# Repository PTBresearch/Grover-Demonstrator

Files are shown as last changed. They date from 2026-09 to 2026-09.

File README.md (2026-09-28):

# Grover-Demonstrator
A simple hardware demonstrator to let the user experience classical search in unstructured data, vs the Grover quantum computer algorithm.

## What can it be used for?

- [Showing how (computationally) hard it is to find something in unstructured data](#showing-how-computationally-hard-it-is-to-find-something-in-unstructured-data)
- [Showing the "quantum advantage" that the Grover algorithm can provide](#showing-the-quantum-advantage-that-the-grover-algorithm-can-provide)
- [Showing the relationship between shots and the probability distribution](#showing-the-relationship-between-shots-and-the-probability-distribution)
- [Showing the impact of noise on the results of quantum computers / the Grover algorithm](#showing-the-impact-of-noise-on-the-results-of-quantum-computers--the-grover-algorithm)
- [Attracting people to a booth by having it blink](#attracting-people-to-a-booth-by-having-it-blink)

## Device overview

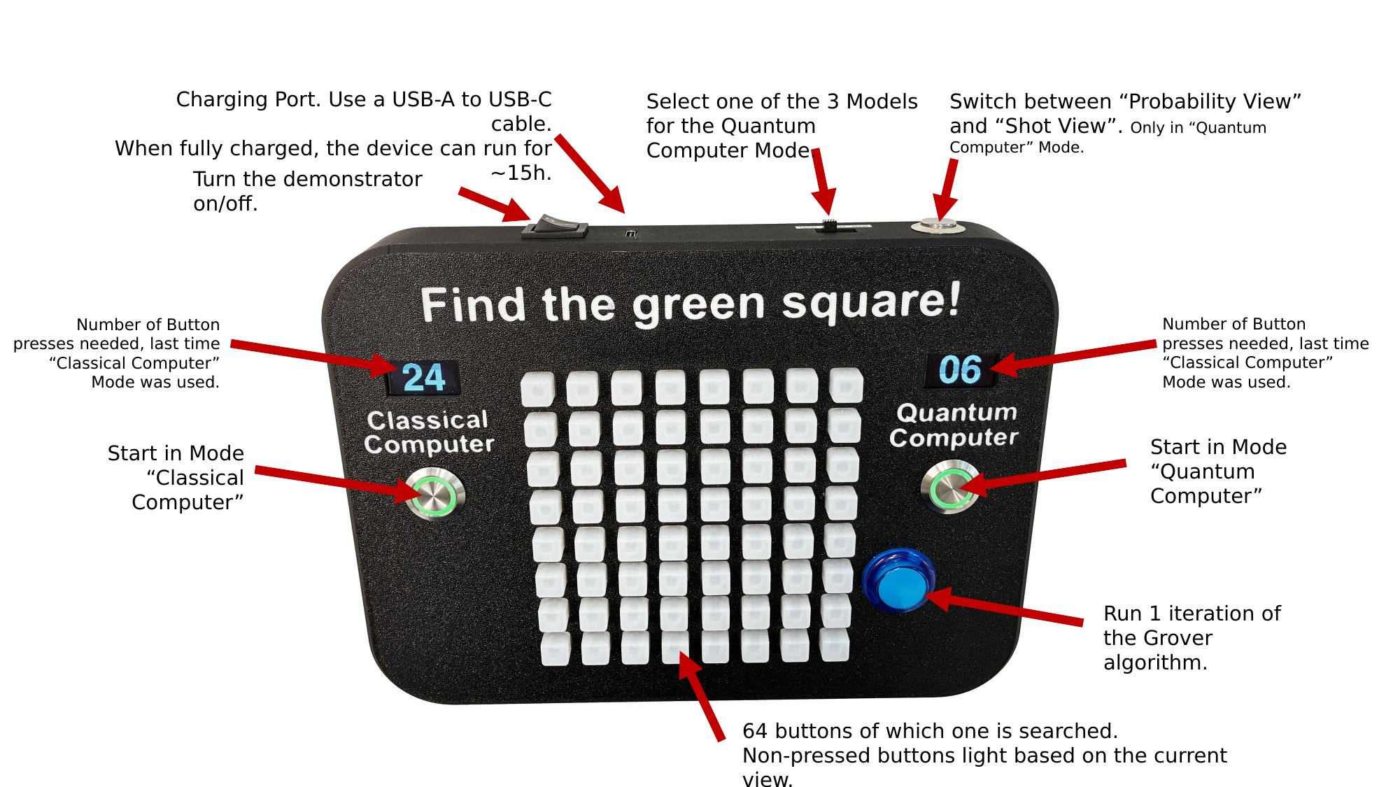
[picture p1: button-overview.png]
Annotated overview of the Grover Demonstrator


| Control | Description |
|---|---|
| On/off switch (top) | Turns the demonstrator on/off. |
| Charging port (top) | Use a USB-A to USB-C cable. When fully charged, the device can run for ~15 h. |
| Model slider (top) | Selects one of the 3 models for "Quantum Computer" mode. |
| Round button (top right) | Switches between "Probability View" and "Shot View". Only in "Quantum Computer" mode. |
| "Classical Computer" button | Starts in "Classical Computer" mode. |
| "Quantum Computer" button | Starts in "Quantum Computer" mode. |
| Left display | Number of button presses needed the last time "Classical Computer" mode was used. |
| Right display | Number of button presses needed the last time "Quantum Computer" mode was used. |
| Blue button | Runs 1 iteration of the Grover algorithm. |
| 8 × 8 button grid | 64 buttons, one of which is searched. Non-pressed buttons light up based on the current view. |

## Showing how (computationally) hard it is to find something in unstructured data

1. Start the demonstrator in "Classical Computer" mode and give it to a user.
2. Their task is to find the one button (of the 64 square ones) that blinks green when pushed.
3. This is an example of search in unstructured data: the user has no idea which button will light green.
4. You can discuss with them that with 64 buttons, they will need 32 tries on average.

A good example of search in unstructured data is guessing a password or decrypting data with no information about the key. You can verify that a solution is correct (you can try to decrypt the data), but there are no strategies to speed up the search. This is different from search problems with structured data, where you can, for example, sort the data to make it easier to search through.

Buttons that have not been pressed glow in a blue hue. The brighter they are, the more likely they are the correct button. As the data are unstructured, all buttons glow equally bright, but they become brighter as fewer buttons are left to be pressed.

> [!TIP]
> If the user found the green button in just a few steps, you can ask them or someone else to try again.

## Showing the "quantum advantage" that the Grover algorithm can provide

1. The user should have used/seen the "Classical Computer" mode already.
2. Make sure the demonstrator uses the **"Ideal"** model.
3. Start "Quantum Computer" mode. The user must again find the green button, ideally with fewer button presses. You can either let them search or do it yourself.

Again, buttons that have not been pressed glow in a blue hue. The brighter they are, the more likely they are the correct button. Initially, all buttons are equally bright, as there is no information about the correct result.

The user can "spend" a button press by pressing the blue button, which causes the Grover search algorithm to improve the prediction of the button that is searched.

When the blue button has been pressed 6 times, the prediction will be best. You can "undo" blue button presses by pressing the "Classical Computer" button. This is sometimes helpful when explaining the algorithm.

Thus, the optimal strategy seems to be to press the blue button once, then the brightest button. This strategy is less ideal with noise and high shot costs.

## Showing the relationship between shots and the probability distribution

1. The user should have used/seen the "Classical Computer" mode already.
2. Start "Quantum Computer" mode. The user must again find the green button, ideally with fewer button presses. You can either let them search or do it yourself.
3. Press the round button at the top of the device to switch to "Shot" mode.

In Shot mode, the buttons do not glow based on their likelihood. Instead, individual shots of the quantum computer are simulated. After the Grover algorithm is computed, the quantum state is read out, resulting in one random result based on the probabilities given by the quantum state of the qubits.

This mode makes it much more difficult to find the correct result without the ideal number of Grover algorithm iterations (blue button presses), especially when the "Real" model is used.

## Showing the impact of noise on the results of quantum computers / the Grover algorithm

1. The user should have used/seen the "Classical Computer" mode already.
2. Start "Quantum Computer" mode. The user must again find the green button, ideally with fewer button presses. You can either let them search or do it yourself.
3. When the blue Grover button has been pressed a few times, use the slider at the top to change between models:
   - **Ideal**: Simulation of a quantum computer without any noise/errors.
   - **Model**: Simple error model that introduces some gate errors.
   - **Real**: Results from a real IBM quantum computer.

The difference between the models is most easily visible when the buttons show probabilities, but Shot mode can also be used.

## Attracting people to a booth by having it blink

1. Start the device in "Quantum Computer" mode and press the round button on the top to switch to "Shot" mode.
2. Place the demonstrator so people can see the buttons blinking.

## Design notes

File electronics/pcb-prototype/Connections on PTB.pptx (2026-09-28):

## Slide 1

Displays

Trellis

BTN2

BTN3

BTN1

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
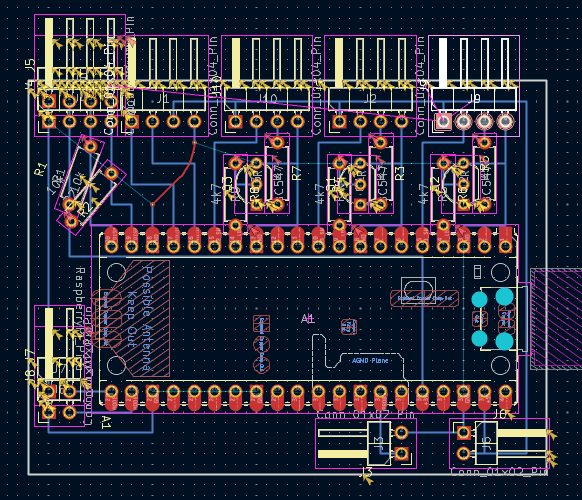
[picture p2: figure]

GND

GND

MODEL_1

MODEL_3

GND

GND

PROB_SW

5V

5V

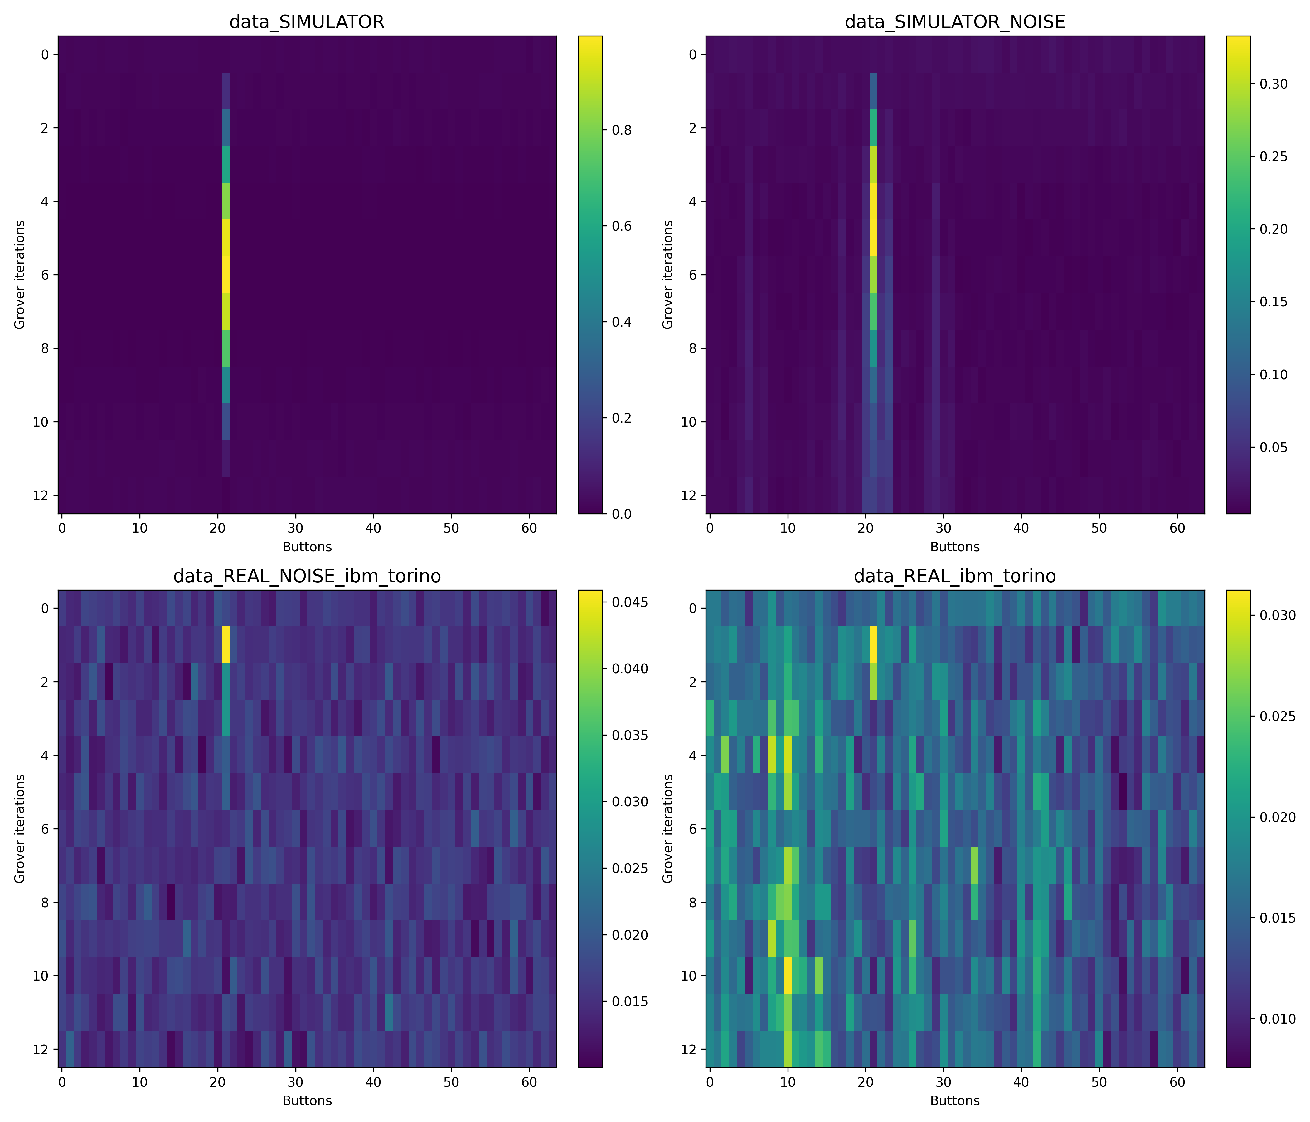
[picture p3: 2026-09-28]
qiskit/heatmaps.png

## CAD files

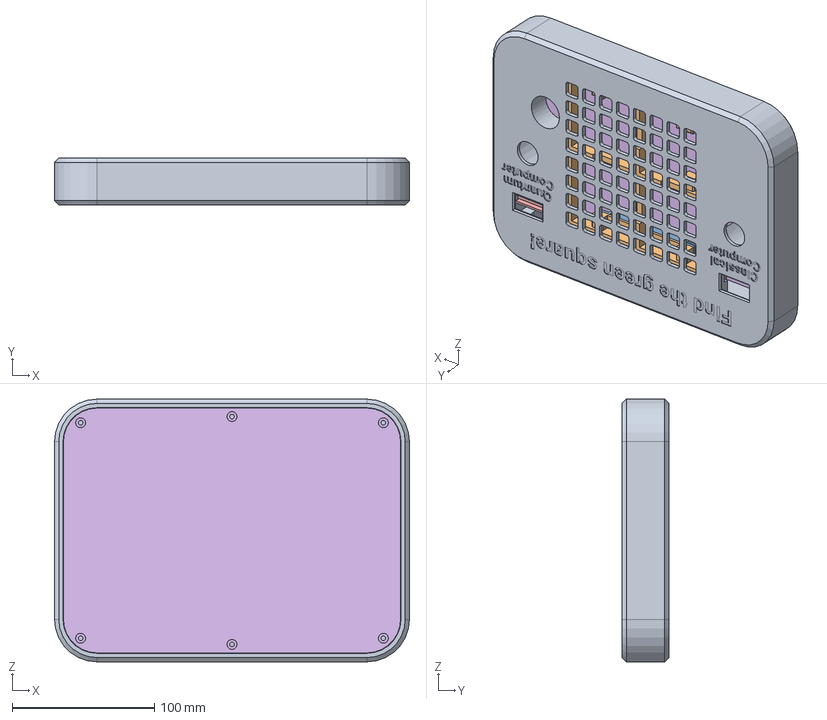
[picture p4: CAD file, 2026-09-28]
case/Grover.step
250.0 x 33.0 x 185.0 mm

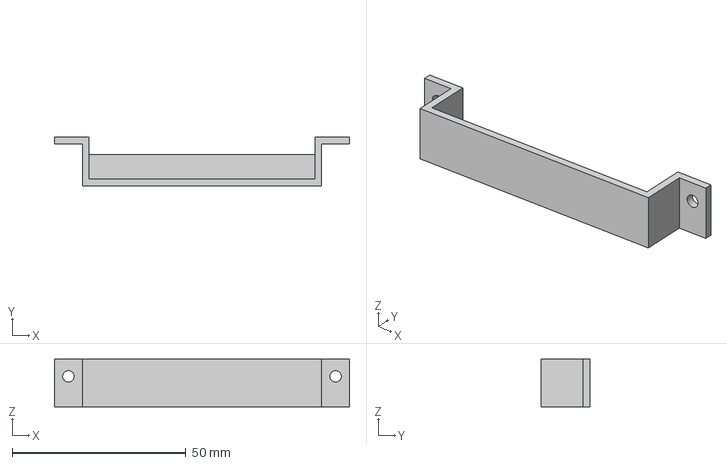
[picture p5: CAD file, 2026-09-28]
case/print files/Grover-v2-Halter-Akku-2x.3mf
85.0 x 14.0 x 13.8 mm

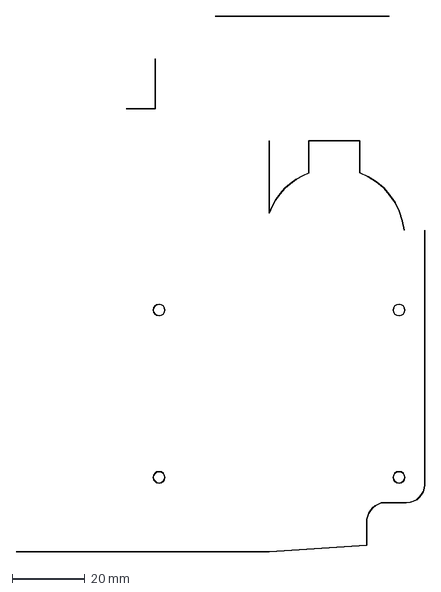
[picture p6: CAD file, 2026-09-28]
electronics/pcb/Skizze-Platine.dxf
112.2 x 147.4 mm

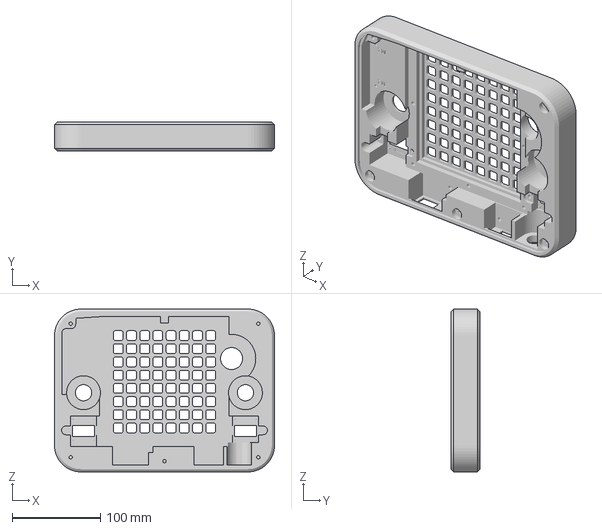
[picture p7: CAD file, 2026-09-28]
case/print files/Grover-v2.1-Gehäuse.3mf
250.0 x 33.0 x 185.0 mm

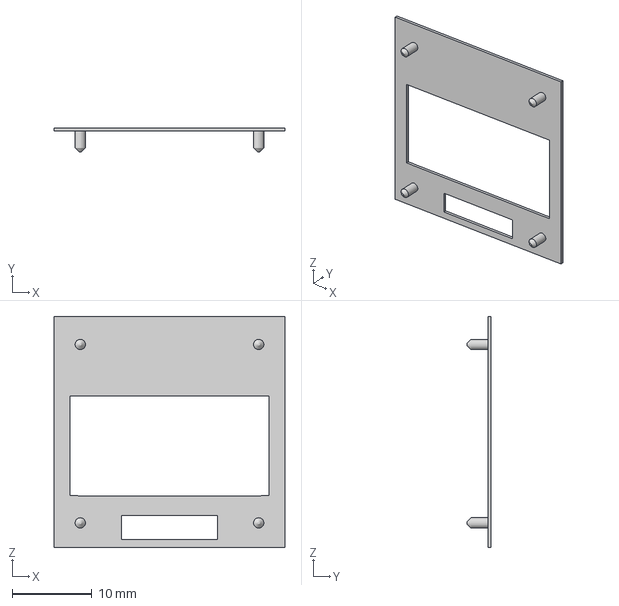
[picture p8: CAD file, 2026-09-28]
case/print files/Grover-v2-Zwischenplatte-Display.3mf
29.0 x 3.00 x 29.0 mm

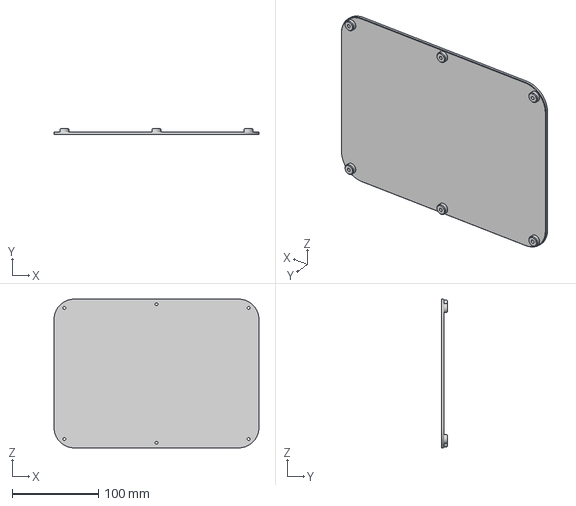
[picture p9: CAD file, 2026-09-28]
case/print files/Grover-v2-Backplate.3mf
237.4 x 6.70 x 172.4 mm

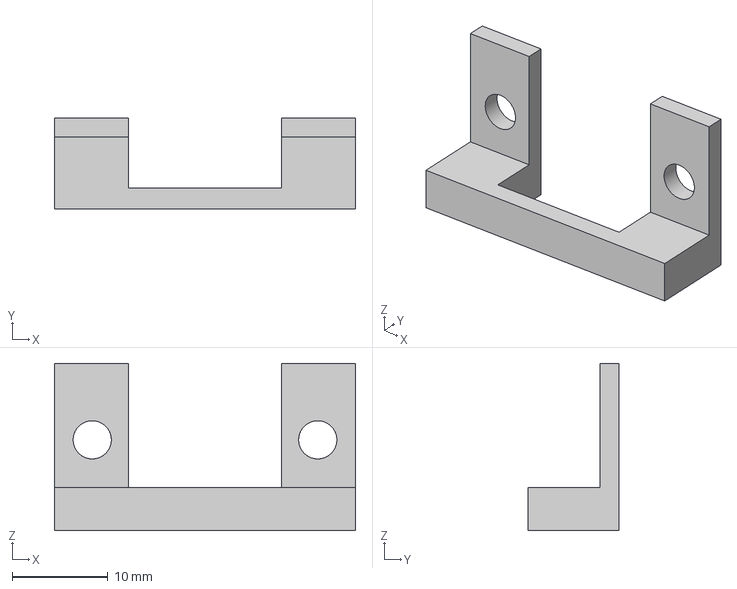
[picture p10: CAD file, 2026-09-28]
case/print files/Grover-v2-Halter-Schalter.3mf
31.5 x 9.50 x 17.5 mm

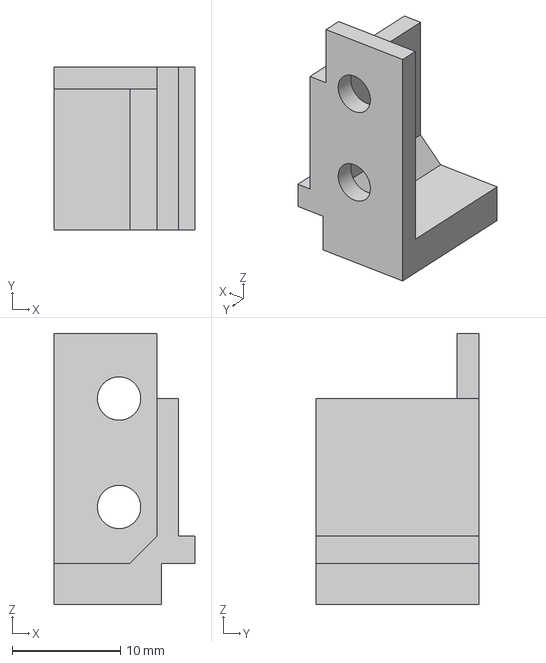
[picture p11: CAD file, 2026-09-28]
case/print files/Grover-v2-Halter-USB.3mf
13.0 x 15.0 x 25.0 mm

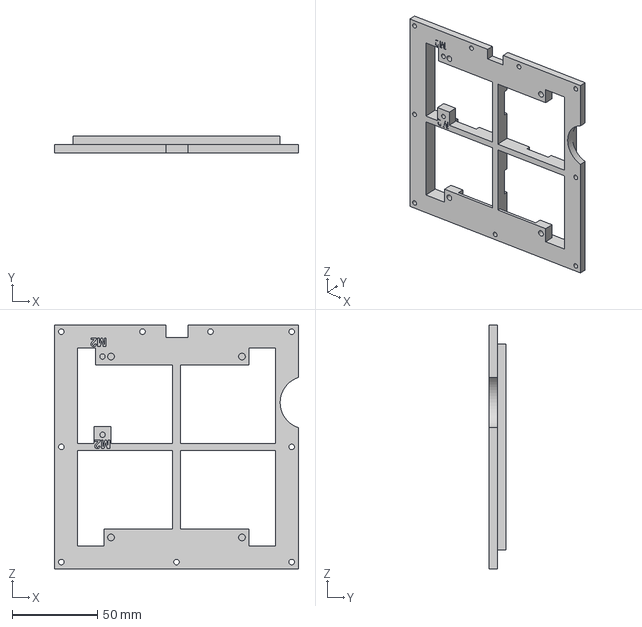
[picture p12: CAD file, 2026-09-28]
case/print files/Grover-v2-Halter-Trellis-1x.3mf
143.5 x 10.0 x 143.4 mm

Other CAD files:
case/print files/Grover-v2-Gehäuse.3mf
case/Grover.f3d

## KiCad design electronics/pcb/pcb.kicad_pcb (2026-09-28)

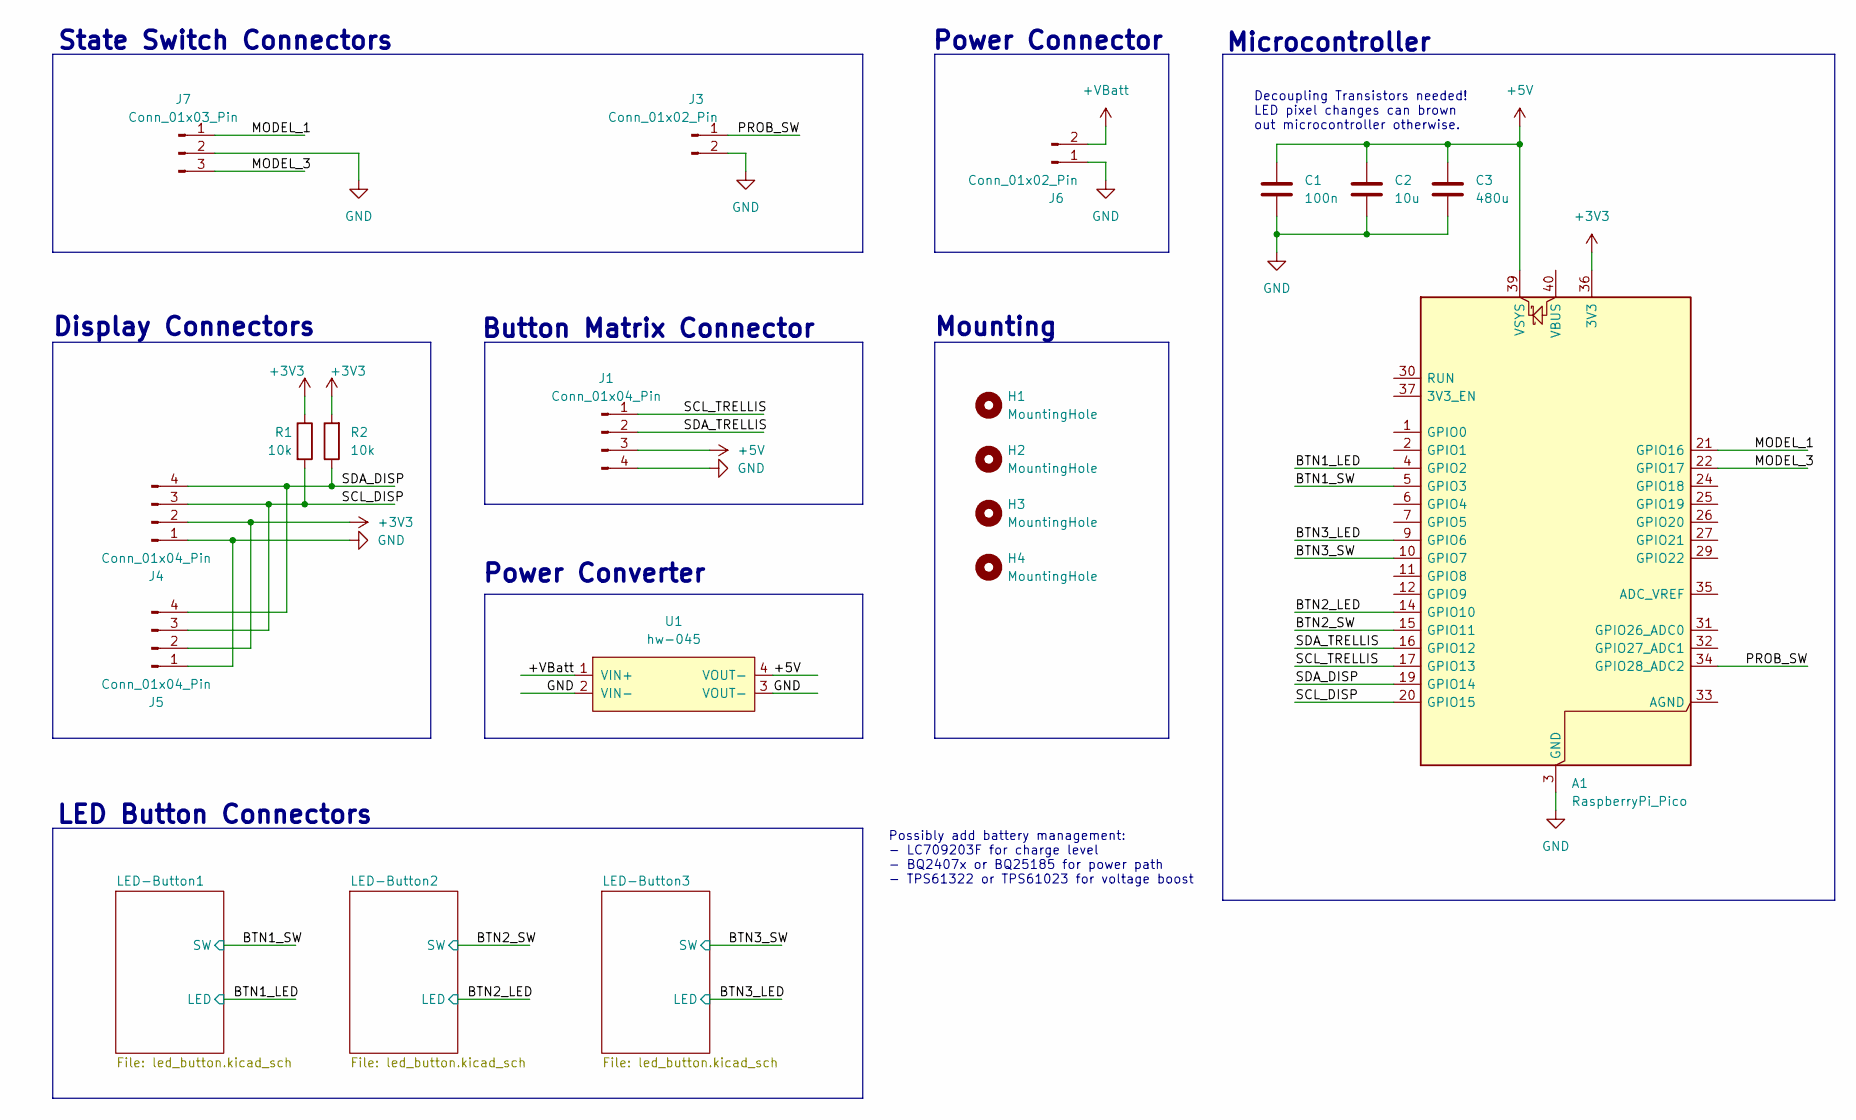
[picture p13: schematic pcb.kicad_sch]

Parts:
A1: RaspberryPi_Pico; RaspberryPi_Pico_Common_Unspecified
C1: 100n; C_Disc_D7.5mm_W5.0mm_P5.00mm
C2: 10u; CP_Radial_D5.0mm_P2.00mm
C3: 480u; CP_Radial_D12.5mm_P5.00mm
H1, H2, H3, H4: MountingHole; MountingHole_2.2mm_M2
J1, J4, J5: Conn_01x04_Pin; JST_PH_S4B-PH-K_1x04_P2.00mm_Horizontal
J3, J6: Conn_01x02_Pin; JST_PH_S2B-PH-K_1x02_P2.00mm_Horizontal
J7: Conn_01x03_Pin; JST_PH_S3B-PH-K_1x03_P2.00mm_Horizontal
R1, R2: 10k; R_Axial_DIN0309_L9.0mm_D3.2mm_P12.70mm_Horizontal
U1: hw-045

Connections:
+3V3: A1.36 (3V3), J4.2, J5.2, R1.1, R2.2
+5V: A1.39 (VSYS), C1.1, C2.1, C3.1, J1.3, U1.4 (VOUT-); also elsewhere on the board
+VBatt: J6.2, U1.1 (VIN+)
/BTN1_LED: A1.4 (GPIO2); also elsewhere on the board
/BTN1_SW: A1.5 (GPIO3); also elsewhere on the board
/BTN2_LED: A1.14 (GPIO10); also elsewhere on the board
/BTN2_SW: A1.15 (GPIO11); also elsewhere on the board
/BTN3_LED: A1.9 (GPIO6); also elsewhere on the board
/BTN3_SW: A1.10 (GPIO7); also elsewhere on the board
/MODEL_1: A1.21 (GPIO16), J7.1
/MODEL_3: A1.22 (GPIO17), J7.3
/PROB_SW: A1.34 (GPIO28_ADC2), J3.1
/SCL_DISP: A1.20 (GPIO15), J4.3, J5.3, R1.2
/SCL_TRELLIS: A1.17 (GPIO13), J1.1
/SDA_DISP: A1.19 (GPIO14), J4.4, J5.4, R2.1
/SDA_TRELLIS: A1.16 (GPIO12), J1.2
GND: A1.3 (GND), A1.8 (GND), A1.13 (GND), A1.18 (GND), A1.23 (GND), A1.28 (GND), A1.38 (GND), C1.2, C2.2, C3.2, J1.4, J3.2, J4.1, J5.1, J6.1, J7.2, U1.2 (VIN-), U1.3 (VOUT-); also elsewhere on the board

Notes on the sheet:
Display Connectors
State Switch Connectors
Possibly add battery management: - LC709203F for charge level - BQ2407x or BQ25185 for power path - TPS61322 or TPS61023 for voltage boost
Mounting
Power Converter
Power Connector
LED Button Connectors
Button Matrix Connector
Microcontroller
Decoupling Transistors needed! LED pixel changes can brown out microcontroller otherwise.

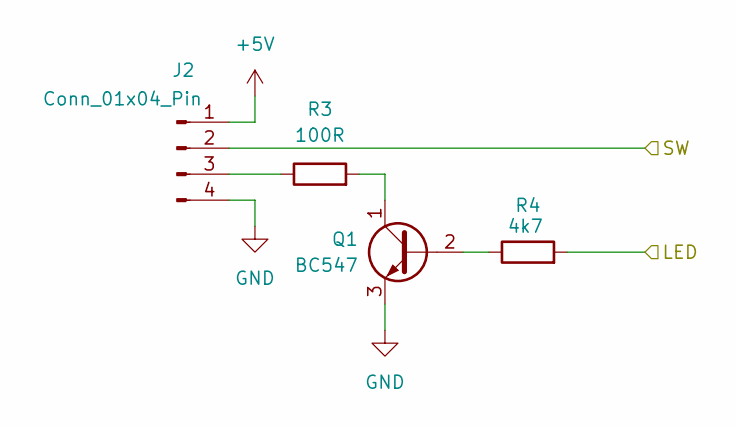
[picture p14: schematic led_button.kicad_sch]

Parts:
J2: Conn_01x04_Pin; JST_PH_S4B-PH-K_1x04_P2.00mm_Horizontal
Q1: BC547; TO-92_Inline_Wide
R3: 100R; R_Axial_DIN0309_L9.0mm_D3.2mm_P12.70mm_Horizontal
R4: 4k7; R_Axial_DIN0309_L9.0mm_D3.2mm_P12.70mm_Horizontal

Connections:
+5V: J2.1; also elsewhere on the board
/BTN3_LED: R4.2; also elsewhere on the board
/BTN3_SW: J2.2; also elsewhere on the board
GND: J2.4, Q1.3 (E); also elsewhere on the board
unnamed: J2.3, R3.1
unnamed: Q1.2 (B), R4.1
unnamed: Q1.1 (C), R3.2

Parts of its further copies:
J9, J10: Conn_01x04_Pin; JST_PH_S4B-PH-K_1x04_P2.00mm_Horizontal
Q2, Q3: BC547; TO-92_Inline_Wide
R5, R7: 100R; R_Axial_DIN0309_L9.0mm_D3.2mm_P12.70mm_Horizontal
R6, R8: 4k7; R_Axial_DIN0309_L9.0mm_D3.2mm_P12.70mm_Horizontal

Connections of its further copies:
+5V: J9.1, J10.1; also elsewhere on the board
/BTN1_LED: R6.2; also elsewhere on the board
/BTN1_SW: J9.2; also elsewhere on the board
/BTN2_LED: R8.2; also elsewhere on the board
/BTN2_SW: J10.2; also elsewhere on the board
GND: J9.4, J10.4, Q2.3 (E), Q3.3 (E); also elsewhere on the board
unnamed: J9.3, R5.1
unnamed: J10.3, R7.1
unnamed: Q2.2 (B), R6.1
unnamed: Q2.1 (C), R5.2
unnamed: Q3.2 (B), R8.1
unnamed: Q3.1 (C), R7.2

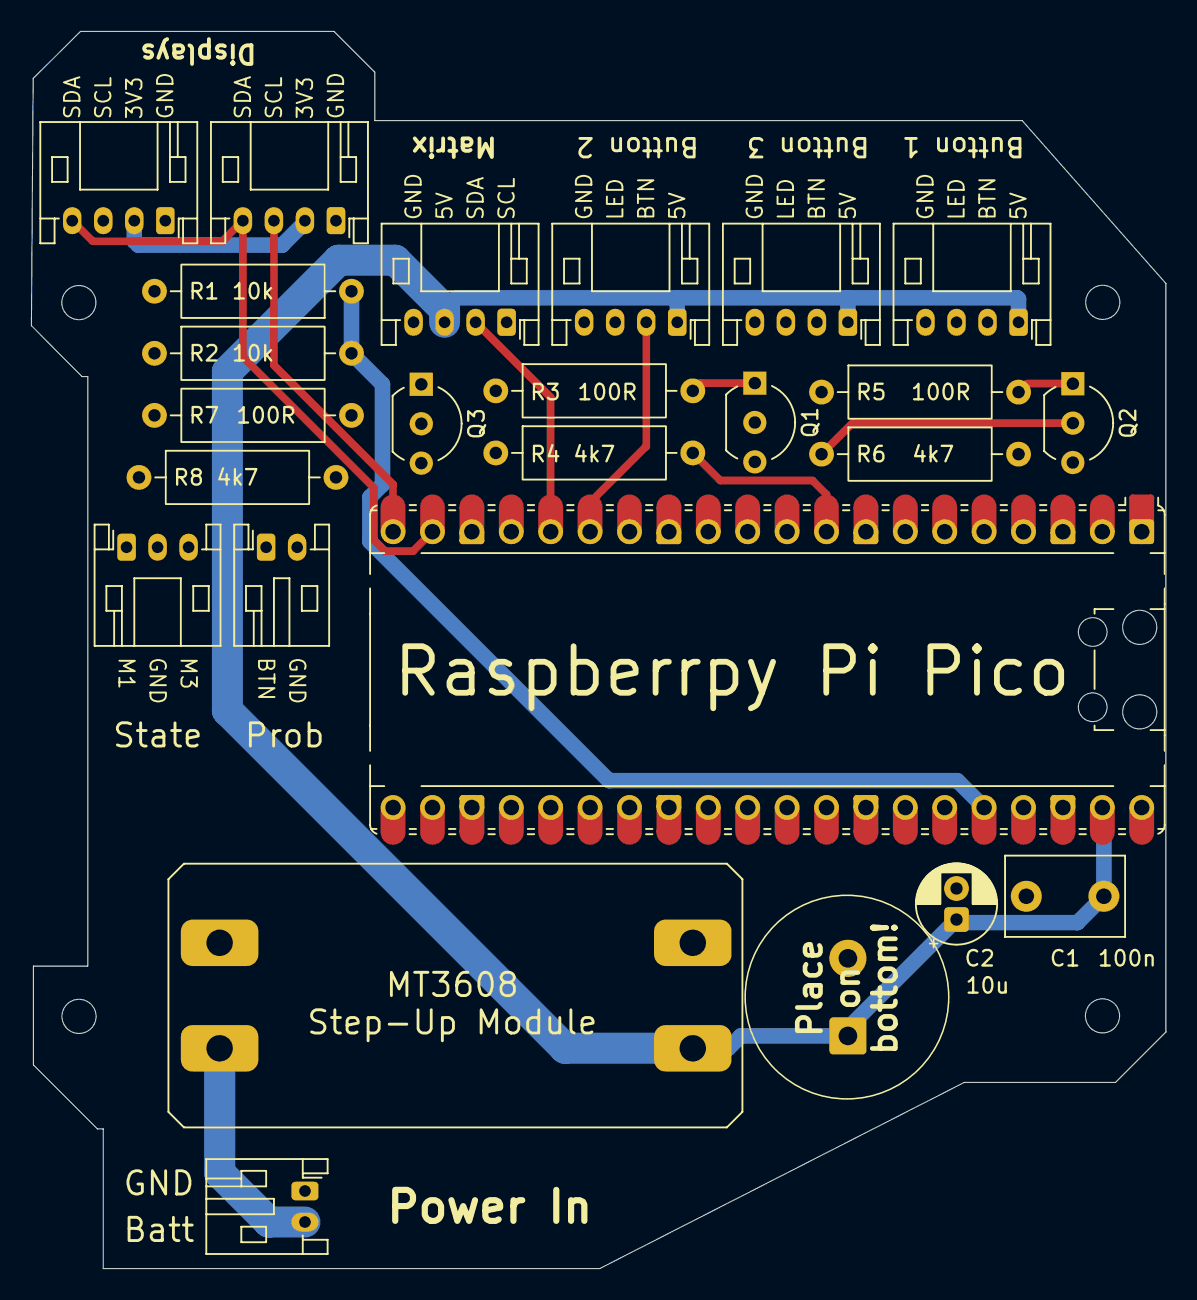
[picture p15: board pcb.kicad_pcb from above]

Board: 4 copper layers, 73.1 x 79.8 mm, 29 parts (1 on the bottom side), 26 nets.

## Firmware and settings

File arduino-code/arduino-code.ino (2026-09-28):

/*

  Code written by Dion Timmermann dion.timmermann@ptb.de 

  This code requires the 
    Raspberry Pi Pico/RP2040/RP2350 Board by Earle F. Philhower.
  Other boards for the Pi Pico do not support assigning random pins for the two IC2 busses!
  
  To installthe Raspberry Pi Pico/RP2040/RP2350 Board:
    - In the arduino IDE. File->Preferences under "Additional boards manager URLs" add
        https://github.com/earlephilhower/arduino-pico/releases/download/global/package_rp2040_index.json
    - Go to the Boards Manager and Install
        "Raspberry Pi Pico/RP2040/RP2350"
    - Select the Board "Raspberry Pi Pico/RP2040/RP2350" -> "Raspberry Pi Pico" (for hand-soldered board).

  Required Libraries:
    - Adafruit SSD1306 by Adafruit
    - Adafruit seesaw Library
    (possibly others)

*/


#include <Wire.h>
#include <Adafruit_NeoTrellis.h>
#include <Adafruit_SSD1306.h>
#include <Adafruit_GFX.h>
#include <algorithm>
#include "FreeSansBold40pt7b.h"
#include "probabilities.h"

const uint32_t infernoLUT[256] PROGMEM = {
  0x000003UL, 0x000004UL, 0x000006UL, 0x010007UL, 0x010109UL, 0x01010BUL, 0x02010EUL, 0x020210UL, 0x030212UL, 0x040314UL, 0x040316UL, 0x050418UL, 0x06041BUL, 0x07051DUL, 0x08061FUL, 0x090621UL,
  0x0A0723UL, 0x0B0726UL, 0x0D0828UL, 0x0E082AUL, 0x0F092DUL, 0x10092FUL, 0x120A32UL, 0x130A34UL, 0x140B36UL, 0x160B39UL, 0x170B3BUL, 0x190B3EUL, 0x1A0B40UL, 0x1C0C43UL, 0x1D0C45UL, 0x1F0C47UL,
  0x200C4AUL, 0x220B4CUL, 0x240B4EUL, 0x260B50UL, 0x270B52UL, 0x290B54UL, 0x2B0A56UL, 0x2D0A58UL, 0x2E0A5AUL, 0x300A5CUL, 0x32095DUL, 0x34095FUL, 0x350960UL, 0x370961UL, 0x390962UL, 0x3B0964UL,
  0x3C0965UL, 0x3E0966UL, 0x400966UL, 0x410967UL, 0x430A68UL, 0x450A69UL, 0x460A69UL, 0x480B6AUL, 0x4A0B6AUL, 0x4B0C6BUL, 0x4D0C6BUL, 0x4F0D6CUL, 0x500D6CUL, 0x520E6CUL, 0x530E6DUL, 0x550F6DUL,
  0x570F6DUL, 0x58106DUL, 0x5A116DUL, 0x5B116EUL, 0x5D126EUL, 0x5F126EUL, 0x60136EUL, 0x62146EUL, 0x63146EUL, 0x65156EUL, 0x66156EUL, 0x68166EUL, 0x6A176EUL, 0x6B176EUL, 0x6D186EUL, 0x6E186EUL,
  0x70196EUL, 0x72196DUL, 0x731A6DUL, 0x751B6DUL, 0x761B6DUL, 0x781C6DUL, 0x7A1C6DUL, 0x7B1D6CUL, 0x7D1D6CUL, 0x7E1E6CUL, 0x801F6BUL, 0x811F6BUL, 0x83206BUL, 0x85206AUL, 0x86216AUL, 0x88216AUL,
  0x892269UL, 0x8B2269UL, 0x8D2369UL, 0x8E2468UL, 0x902468UL, 0x912567UL, 0x932567UL, 0x952666UL, 0x962666UL, 0x982765UL, 0x992864UL, 0x9B2864UL, 0x9C2963UL, 0x9E2963UL, 0xA02A62UL, 0xA12B61UL,
  0xA32B61UL, 0xA42C60UL, 0xA62C5FUL, 0xA72D5FUL, 0xA92E5EUL, 0xAB2E5DUL, 0xAC2F5CUL, 0xAE305BUL, 0xAF315BUL, 0xB1315AUL, 0xB23259UL, 0xB43358UL, 0xB53357UL, 0xB73456UL, 0xB83556UL, 0xBA3655UL,
  0xBB3754UL, 0xBD3753UL, 0xBE3852UL, 0xBF3951UL, 0xC13A50UL, 0xC23B4FUL, 0xC43C4EUL, 0xC53D4DUL, 0xC73E4CUL, 0xC83E4BUL, 0xC93F4AUL, 0xCB4049UL, 0xCC4148UL, 0xCD4247UL, 0xCF4446UL, 0xD04544UL,
  0xD14643UL, 0xD24742UL, 0xD44841UL, 0xD54940UL, 0xD64A3FUL, 0xD74B3EUL, 0xD94D3DUL, 0xDA4E3BUL, 0xDB4F3AUL, 0xDC5039UL, 0xDD5238UL, 0xDE5337UL, 0xDF5436UL, 0xE05634UL, 0xE25733UL, 0xE35832UL,
  0xE45A31UL, 0xE55B30UL, 0xE65C2EUL, 0xE65E2DUL, 0xE75F2CUL, 0xE8612BUL, 0xE9622AUL, 0xEA6428UL, 0xEB6527UL, 0xEC6726UL, 0xED6825UL, 0xED6A23UL, 0xEE6C22UL, 0xEF6D21UL, 0xF06F1FUL, 0xF0701EUL,
  0xF1721DUL, 0xF2741CUL, 0xF2751AUL, 0xF37719UL, 0xF37918UL, 0xF47A16UL, 0xF57C15UL, 0xF57E14UL, 0xF68012UL, 0xF68111UL, 0xF78310UL, 0xF7850EUL, 0xF8870DUL, 0xF8880CUL, 0xF88A0BUL, 0xF98C09UL,
  0xF98E08UL, 0xF99008UL, 0xFA9107UL, 0xFA9306UL, 0xFA9506UL, 0xFA9706UL, 0xFB9906UL, 0xFB9B06UL, 0xFB9D06UL, 0xFB9E07UL, 0xFBA007UL, 0xFBA208UL, 0xFBA40AUL, 0xFBA60BUL, 0xFBA80DUL, 0xFBAA0EUL,
  0xFBAC10UL, 0xFBAE12UL, 0xFBB014UL, 0xFBB116UL, 0xFBB318UL, 0xFBB51AUL, 0xFBB71CUL, 0xFBB91EUL, 0xFABB21UL, 0xFABD23UL, 0xFABF25UL, 0xFAC128UL, 0xF9C32AUL, 0xF9C52CUL, 0xF9C72FUL, 0xF8C931UL,
  0xF8CB34UL, 0xF8CD37UL, 0xF7CF3AUL, 0xF7D13CUL, 0xF6D33FUL, 0xF6D542UL, 0xF5D745UL, 0xF5D948UL, 0xF4DB4BUL, 0xF4DC4FUL, 0xF3DE52UL, 0xF3E056UL, 0xF3E259UL, 0xF2E45DUL, 0xF2E660UL, 0xF1E864UL,
  0xF1E968UL, 0xF1EB6CUL, 0xF1ED70UL, 0xF1EE74UL, 0xF1F079UL, 0xF1F27DUL, 0xF2F381UL, 0xF2F485UL, 0xF3F689UL, 0xF4F78DUL, 0xF5F891UL, 0xF6FA95UL, 0xF7FB99UL, 0xF9FC9DUL, 0xFAFDA0UL, 0xFCFEA4UL
};

#define MAX_GROVER_STEP 12

uint32_t heatmap(uint8_t idx) {
  // Read packed RGB from flash
  uint8_t safeIdx = (idx > 255) ? 255 : idx;
  uint32_t color = pgm_read_dword(&infernoLUT[safeIdx]);
  
  // Extract RGB components
  uint8_t r = (color >> 16) & 0xFF;
  uint8_t g = (color >> 8) & 0xFF;
  uint8_t b = color & 0xFF;
  
  // Reduce brightness to 25% to prevent power issues
  r = r / 4;
  g = g / 4;
  b = b / 4;
  
  // Recombine into 32-bit color
  return ((uint32_t)r << 16) | ((uint32_t)g << 8) | b;
}

// Wire bus (I2C0) pins for NeoTrellis
#define TRELLIS_SDA 12
#define TRELLIS_SCL 13

// Wire1 bus (I2C1) pins for SSD1306s
#define OLED_SDA 14
#define OLED_SCL 15

// SSD1306 display addresses
#define OLED1_ADDR 0x3C
#define OLED2_ADDR 0x3D
#define SCREEN_WIDTH 128
#define SCREEN_HEIGHT 64

#define PIXELS_PER_ROW 8

Adafruit_SSD1306 displayClassic(SCREEN_WIDTH, SCREEN_HEIGHT, &Wire1);
Adafruit_SSD1306 displayQuantum(SCREEN_WIDTH, SCREEN_HEIGHT, &Wire1);

// Assuming you have 4 NeoTrellis boards connected on the same bus
#define NUM_BOARDS_X 2
#define NUM_BOARDS_Y 2

#define LED_CLASSIC 2
#define BTN_CLASSIC 3
#define LED_QUANTUM 6
#define BTN_QUANTUM 7
#define LED_GROVER 10
#define BTN_GROVER 11

#define BTN_PROB 28
#define SW_MODE_1 16
#define SW_MODE_3 17

void flashAllMultiTrellis(uint32_t color = 0xFFFFFF, uint16_t delayMs = 5, uint8_t times = 3);

const uint16_t totalKeys = NUM_BOARDS_X * NUM_BOARDS_Y * NEO_TRELLIS_NUM_KEYS;

bool wasPressed[totalKeys];
uint8_t brightness[totalKeys];
long counter;
uint8_t goal;
uint8_t random_offset;
long groverStep;
uint8_t model = 0;

uint16_t currentProbabilities[64];
uint16_t currentCumsum[64];
void updateProbabilities() {
    uint8_t model_clamped = std::clamp(model, (uint8_t) 0, (uint8_t) 2);
    long step_clamped = std::clamp(groverStep, (long) 0, (long) 12);

    for (uint8_t i = 0; i < 64; i++) {
        // Use pgm_read_word to read from PROGMEM
        currentProbabilities[i] = pgm_read_word(&(probabilities[model_clamped][step_clamped][i]));
    }

    // Compute cumulative sum
    currentCumsum[0] = currentProbabilities[0];
    for (uint8_t i = 1; i < 64; i++) {
      currentCumsum[i] = currentCumsum[i-1] + currentProbabilities[i];
    }
}

uint8_t randomShot() {

  // Generate random number from 0 to total sum - 1
  uint16_t total = currentCumsum[63];
  uint16_t r = random(0L, total);

  for (uint8_t i = 0; i < 64; i++) {
      if (r < currentCumsum[i]) return i;
  }
  return 63;  // fallback
}

// Addresses of each board
Adafruit_NeoTrellis trellis_boards[NUM_BOARDS_Y][NUM_BOARDS_X] = {
  { Adafruit_NeoTrellis(0x2E, &Wire), Adafruit_NeoTrellis(0x2F, &Wire) },
  { Adafruit_NeoTrellis(0x30, &Wire), Adafruit_NeoTrellis(0x31, &Wire) }
};

Adafruit_MultiTrellis trellis((Adafruit_NeoTrellis *)trellis_boards, NUM_BOARDS_Y, NUM_BOARDS_X);

void setPixel(uint8_t index, uint8_t r, uint8_t g, uint8_t b) {
  uint8_t row = index / PIXELS_PER_ROW;
  uint8_t col = index % PIXELS_PER_ROW;
}

void displayNumber(Adafruit_SSD1306 &display, int number) {
  // Clamp number to 0-99
  if (number < 0) number = 0;
  if (number > 99) number = 99;

  display.clearDisplay();
  display.setFont(&FreeSansBold40pt7b);
  display.setTextColor(SSD1306_WHITE);

  // Convert number to string
  char buf[3];
  sprintf(buf, "%02d", number);

  // Measure text bounds
  int16_t x1, y1;
  uint16_t w, h;
  display.getTextBounds(buf, 0, 0, &x1, &y1, &w, &h);

  // Center text
  int16_t x = (display.width() - w) / 2 - x1;
  int16_t y = (display.height() - h) / 2 - y1;

  display.setCursor(x, y);
  display.print(buf);
  display.display();
}

#define TOTAL_KEYS (NUM_BOARDS_X * NUM_BOARDS_Y * NEO_TRELLIS_NUM_KEYS)
bool keyPressed[TOTAL_KEYS]; // global array to track button states

// Callback for MultiTrellis keys
TrellisCallback keyPressCallback(keyEvent evt) {
    int keyNum = evt.bit.NUM;
    if (evt.bit.EDGE == SEESAW_KEYPAD_EDGE_RISING) {
        keyPressed[keyNum] = true;
    } else {
        keyPressed[keyNum] = false;
    }
    return nullptr;
}

// Returns unique button number if exactly one button is pressed
int getSinglePressedButton() {
    trellis.read();
    int pressedButton = -1;
    for (int i = 0; i < TOTAL_KEYS; i++) {
        if (keyPressed[i]) {
            if (pressedButton == -1) {
                pressedButton = i;
            } else {
                return -1; // more than one pressed
            }
        }
    }
    return pressedButton;
}

void setAllPixels(uint32_t color) {
  for (uint16_t i = 0; i < totalKeys; i++) {
    trellis.setPixelColor(i, color);
  }
  trellis.show();
}

void setSinglePixel(uint16_t pixel, uint32_t color) {
  trellis.setPixelColor(pixel, color);
  trellis.show();
}

inline bool isPressed(uint8_t button) {
  return !digitalRead(button);
}

const uint8_t gammaSteps = 20;
uint8_t gammaTable[gammaSteps];

void setupGamma() {
  const float gamma = 3.3;
  for (uint8_t i = 0; i < gammaSteps; i++) {
    float normalized = (float)i / (gammaSteps - 1); // 0..1
    gammaTable[i] = round(pow(normalized, gamma) * 255.0); // 0..255
  }
}



void setup() {
  Serial.begin(9600);
  delay(2000);
  Serial.println("Starting dual I2C test...");

  // Init I2C0 for Trellis
  Wire.setSDA(12);
  Wire.setSCL(13);
  Wire.begin();
  // Wire.setClock(400000);

  // Init I2C1 for Displays
  Wire1.setSDA(14);
  Wire1.setSCL(15);
  Wire1.begin();

  // Setup Trellis
  trellis.begin();

  for (int y = 0; y < PIXELS_PER_ROW; y++) {
    for (int x = 0; x < PIXELS_PER_ROW; x++) {
      trellis.activateKey(x, y, SEESAW_KEYPAD_EDGE_RISING, true);
      trellis.activateKey(x, y, SEESAW_KEYPAD_EDGE_FALLING, true);
      trellis.registerCallback(x, y, keyPressCallback);
    }
  }
  for (int i = 0; i < TOTAL_KEYS; i++) {
    keyPressed[i] = false;
  }

  // Setup LEDs
  pinMode(LED_CLASSIC, OUTPUT);
  pinMode(LED_QUANTUM, OUTPUT);
  pinMode(LED_GROVER,  OUTPUT);

  // Setup Buttons
  pinMode(BTN_CLASSIC, INPUT_PULLUP);
  pinMode(BTN_QUANTUM, INPUT_PULLUP);
  pinMode(BTN_GROVER,  INPUT_PULLUP);

  pinMode(BTN_PROB,   INPUT_PULLUP);
  pinMode(SW_MODE_1,  INPUT_PULLUP);
  pinMode(SW_MODE_3,  INPUT_PULLUP);

  // Setup Displays
  displayClassic.begin(SSD1306_SWITCHCAPVCC, OLED1_ADDR);
  displayClassic.clearDisplay();
  displayClassic.display();

  displayQuantum.begin(SSD1306_SWITCHCAPVCC, OLED2_ADDR);
  displayQuantum.clearDisplay();
  displayQuantum.display();

  setupGamma();

}

void winAnimation() {

  // Flash goal
  for (int i=0; i<5; i++) {
    delay(200);
    setSinglePixel(goal, 0x000000);
    delay(200);
    setSinglePixel(goal, 0x00FF00);
  }
  delay(100);

  // Fill all others in increasingly big red diamonds.
  int goal_y = goal / 8;
  int goal_x = goal % 8;
  for (int d_step=1; d_step<16; d_step++) {
    for (int i=0; i<64; i++) {
      int y = i / 8;
      int x = i % 8;
      
      int d = abs(goal_x - x) + abs(goal_y - y);
      if (d == d_step) {
        if (!wasPressed[i]) {
          trellis.setPixelColor(i, 0x030000);
        }  
      }
    }
    trellis.show();
    delay(100);
  }
  
  delay(1000);

}

void classicGame() {

  counter = 0;
  goal = random(0, totalKeys);

  for (int8_t i; i<totalKeys; i++) {
    wasPressed[i] = false;
  }

  setAllPixels(heatmap(255/64));
  while(true) {
    int8_t pressed = getSinglePressedButton();
    if (pressed != -1 && !wasPressed[pressed]) {
      counter += 1;
      displayNumber(displayClassic, counter);

      wasPressed[pressed] = true;
      if (pressed == goal) {
        trellis.setPixelColor(pressed, 0x008F00);
        trellis.show();
        break;
      } else {
        trellis.setPixelColor(pressed, 0x5F0000);
      }
      for (int i=0; i<64; i++) {
        if (!wasPressed[i]) {
          trellis.setPixelColor(i, heatmap(255/(64-counter)));
        }
      }
      trellis.show();
    }
  }

  winAnimation();

}

void setPixelsBasedOnBrightnessMap() {
  for (int16_t i=0; i<totalKeys; i++) {
    if (brightness[i]) {
      brightness[i] -= 1;

      uint8_t b = gammaTable[brightness[i]];
      uint32_t color;

      if (wasPressed[i]) {
        color = (uint32_t) b;

        // Ensure minimal brighness
        if (color < 0x03) {
          color = 0x03;
        }

        // Make it green or red.
        if (i == goal) {
          color = color << 8;
        } else {
          color = color << 16;
        }
      } else {
        b = b/3; // Dimm white pixels by factor of 3 so the are as bright as red and green pixels.
        color = ((uint32_t)b << 16) | ((uint32_t)b << 8) | b;
      }
      
      trellis.setPixelColor(i, color);
    }
  }
  trellis.show();
}

void setPixelsBasedOnProbabilities() {
  for (int16_t i=0; i<totalKeys; i++) {

    int16_t shiftedIndex = (i - random_offset + totalKeys) % totalKeys;
    if (wasPressed[i]) {
      if (i == goal) {
        trellis.setPixelColor(i, 0x00FF00);  
      } else {
        trellis.setPixelColor(i, 0x030000);  
      }
    } else {
      trellis.setPixelColor(i, heatmap(currentProbabilities[shiftedIndex] / 16));
    }
    // trellis.setPixelColor((i + random_offset) % totalKeys, heatmap(currentProbabilities[i] / 16));
  }
  trellis.show();
}

uint8_t readModeButton() {
    if (isPressed(SW_MODE_1)) {
      return 2;
    } else if (isPressed(SW_MODE_3)) {
      return 0;
    } else {
      return 1;
    }
}

// Entprellzeit in ms
const uint16_t DEBOUNCE_MS = 20;

// Globale Variablen pro Button
bool lastButtonState = HIGH;  // HIGH wegen Pull-up
unsigned long lastDebounceTime = 0;

bool readProbabilitiesButton() {
  bool reading = digitalRead(BTN_PROB);

  if (reading != lastButtonState) {
    // Zustand hat sich geändert -> Timer starten
    lastDebounceTime = millis();
  }

  if ((millis() - lastDebounceTime) > DEBOUNCE_MS) {
    // Stabiler Zustand
    static bool buttonStateStable = HIGH;
    if (reading != buttonStateStable) {
      buttonStateStable = reading;
      if (buttonStateStable == LOW) {
        // gedrückt (Pull-up), aber wir wollen RISING edge
        lastButtonState = reading;
        return true;  // steigende Flanke
      }
    }
  }

  lastButtonState = reading;
  return false;
}

void quantumGame() {

  // Setup
  counter = 0;
  random_offset = random(0, totalKeys);
  goal = (21 + random_offset) % totalKeys;//random(0, totalKeys);
  groverStep = 0;

  for (int8_t i; i<totalKeys; i++) {
    wasPressed[i] = false;
  }

  for (int16_t i; i<totalKeys; i++) {
    brightness[i] = 0;
  }

  // Main game

  bool newShot = true;
  uint8_t groverGammaMin = 8;
  uint8_t groverGamma = groverGammaMin;
  bool showProbabilities = true;

  updateProbabilities();
  setPixelsBasedOnProbabilities();
  while (true) {

    uint8_t newModel = readModeButton();
    if (newModel != model) {
      model = newModel;
      updateProbabilities();

      if (showProbabilities) {
        setPixelsBasedOnProbabilities();
      }
    }

    if (readProbabilitiesButton()) {
      showProbabilities = !showProbabilities;
      if (showProbabilities) {
        setPixelsBasedOnProbabilities();
      } else {
        for (int i=0; i<64; i++) {
          if (wasPressed[i]) {
            trellis.setPixelColor(i, 0x030000);
          } else {
            trellis.setPixelColor(i, 0x000000);
          }
        }
        trellis.show();
      }
    }

    int8_t pressed = getSinglePressedButton();
    if (pressed != -1 && !wasPressed[pressed]) {
      counter += 1;
      displayNumber(displayQuantum, counter);

      wasPressed[pressed] = true;
      brightness[pressed] = gammaSteps;

      if (showProbabilities) {
        setPixelsBasedOnProbabilities();
      }
    }

    if (!showProbabilities) {
      if (newShot) {
        int16_t shot = (randomShot() + random_offset) % totalKeys;
        brightness[shot] = gammaSteps;
      }
      newShot = !newShot;

      setPixelsBasedOnBrightnessMap();
    }

    if (pressed == goal) {
      break;
    }

    if (isPressed(BTN_GROVER) && groverGamma == groverGammaMin && groverStep < MAX_GROVER_STEP) {
      groverGamma = gammaSteps;
      counter += 1;
      groverStep +=1;
      updateProbabilities();
      if (showProbabilities) {
        setPixelsBasedOnProbabilities();
      }
      displayNumber(displayQuantum, counter);
    } else if (showProbabilities && isPressed(BTN_CLASSIC) && groverGamma <= groverGammaMin && groverStep > 0) {
      // Secret undo grover step when showing probabilties
      groverGamma = gammaSteps;
      counter -= 1;
      groverStep -=1;
      updateProbabilities();
      if (showProbabilities) {
        setPixelsBasedOnProbabilities();
      }
      displayNumber(displayQuantum, counter);
    }
    if (groverStep < MAX_GROVER_STEP) {
      if (groverGamma > groverGammaMin) {
        groverGamma -= 1;
      }
    } else {
      if (groverGamma > 0) {
        groverGamma -= 1;
      }
    }
    analogWrite(LED_GROVER, gammaTable[groverGamma]);

    delay(17);


  }

  // Fade out all shots, but keep goal bright green
  for (uint8_t i=0; i<gammaSteps; i++) {
    brightness[goal] = gammaSteps;
    setPixelsBasedOnBrightnessMap();

    if (groverGamma > 0) {
      groverGamma -= 1;
    }
    analogWrite(LED_GROVER, gammaTable[groverGamma]);

    delay(17);
  }

  winAnimation();

  // for (uint32_t i=0; i<64; i++) {
  //   trellis.setPixelColor(i, heatmap(i*4));
    
  // }
  //   delay(100);
  //   trellis.show();
  // //   delay(500);


  // while (true) {

  //   if (isPressed(SW_MODE_1)) {
  //     displayNumber(displayQuantum, 1);
  //   }
  //   else if (isPressed(SW_MODE_3)) {
  //     displayNumber(displayQuantum, 3);
  //   } else {
  //     displayNumber(displayQuantum, 2);
  //   }


  // }
}

enum State {
  SELECT_GAME,
  CLASSIC,
  CLASSIC_END,
  QUANTUM,
  QUANTUM_END
};

State currentState = SELECT_GAME;

void loop() {
  if (currentState == SELECT_GAME) {

    setAllPixels(0x000000);
    digitalWrite(LED_CLASSIC, HIGH);
    digitalWrite(LED_QUANTUM, HIGH);
    digitalWrite(LED_GROVER, LOW);

    while (true) {
      if (isPressed(BTN_CLASSIC)) {
        currentState = CLASSIC;
        break;
      }
      if (isPressed(BTN_QUANTUM)) {
        currentState = QUANTUM;
        break;
      }
      delay(10);
    }

  } else if (currentState == CLASSIC) {

    digitalWrite(LED_CLASSIC, LOW);
    digitalWrite(LED_QUANTUM, LOW);

    displayNumber(displayClassic, 0);

    classicGame();
    currentState = SELECT_GAME;

  } else if (currentState == QUANTUM) {

    digitalWrite(LED_CLASSIC, LOW);
    digitalWrite(LED_QUANTUM, LOW);
    analogWrite(LED_GROVER, 30);

    displayNumber(displayQuantum, 0);

    quantumGame();

    displayQuantum.setTextColor(30);
    displayNumber(displayQuantum, counter);
    displayQuantum.setTextColor(255);

    currentState = SELECT_GAME;

  }
}

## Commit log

2026-09-28 Added hardware and software files.
    [Grover-v2-Backplate.3mf, Grover-v2-Gehäuse.3mf, Grover-v2-Halter-Akku-2x.3mf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]
2026-09-28 Enhance README with usage and device details
    Expanded the README with detailed usage instructions and device overview.
2026-09-28 Added new overview of buttons
2026-09-28 Change image filename in device overview section
    Updated image reference in the README file.
